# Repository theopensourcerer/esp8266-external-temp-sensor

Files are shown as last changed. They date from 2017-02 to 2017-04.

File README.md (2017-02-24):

# ESP8266 External Temp Sensor

This is simple board which will connect to one of those DS18B20 temperature sensors which are inside a metal sleeve and designed for external use. 

This board will ultimately live in a box outside my polytunnel with a 12V car battery, charged using solar power. One of the new features of this particular design, for me at least, is using a Switching regulator rather than a nomral LDO Linear regulator. I read that trying to drop from 12v to 3.3v is not effecient at all and can generate a lot of heat using a Linear design.

The board's software (under active testing & development) will take a measurememt, send it over MQTT and go back to sleep. I wanted this so I could compare the temperature between inside my polytunnel (see https://github.com/theopensourcerer/esp8266_envmonitor) and the normal outdoor temperature.

As with the Environment Monitor Project I plan to publish the code and a 3D case for this design. Watch this space!

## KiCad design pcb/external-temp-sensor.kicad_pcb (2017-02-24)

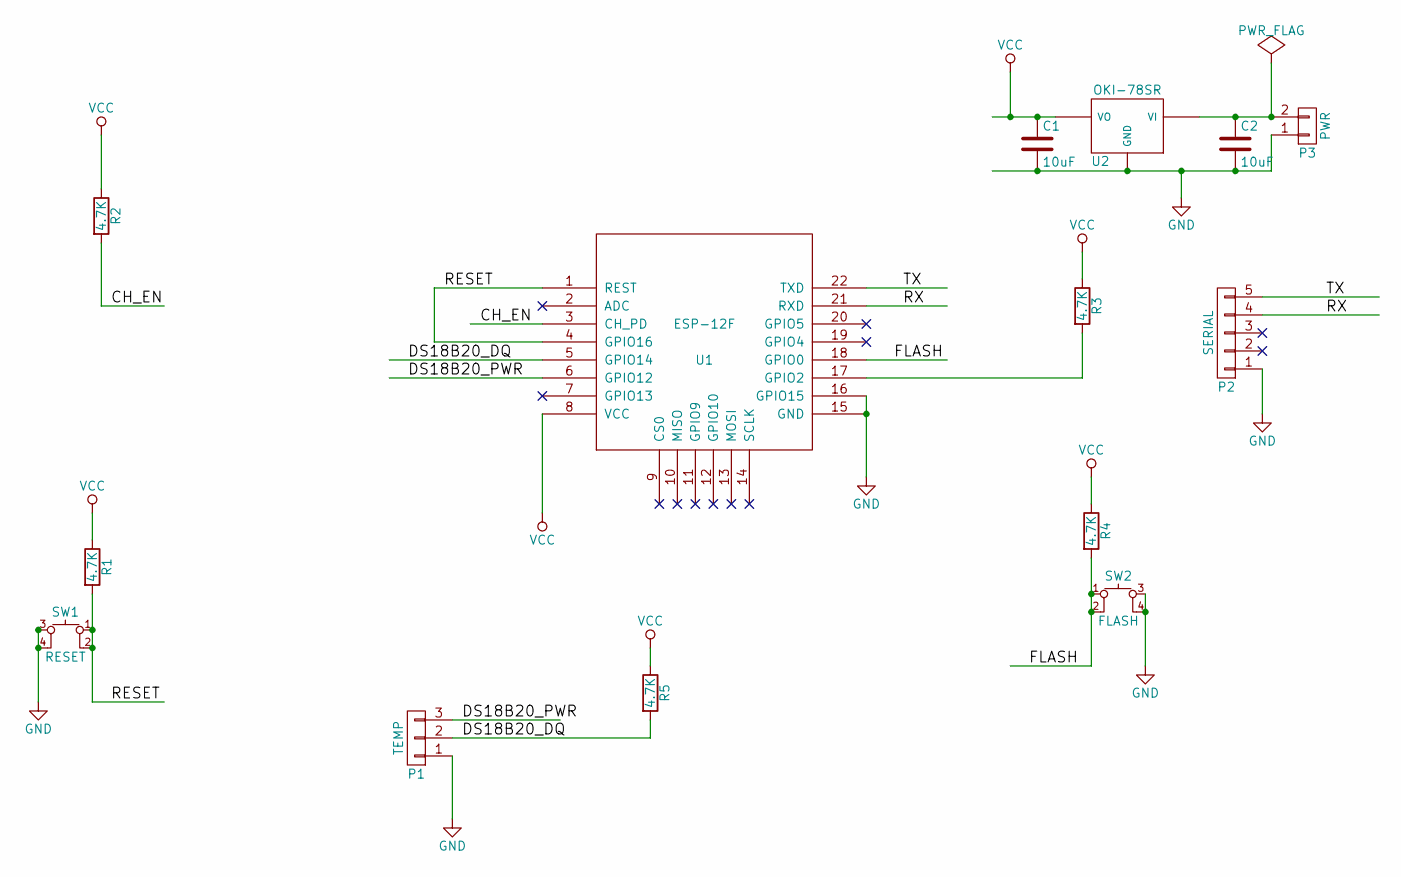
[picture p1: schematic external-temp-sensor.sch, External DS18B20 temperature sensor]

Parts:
C1, C2: 10uF; C_1206_HandSoldering
P1: TEMP; JST_XH_B03B-XH-A_03x2.50mm_Straight
P2: SERIAL; Pin_Header_Straight_1x05_Pitch2.54mm
P3: PWR; JST_XH_B02B-XH-A_02x2.50mm_Straight
R1, R2, R3, R4, R5: 4.7K; R_1206_HandSoldering
SW1: RESET; SKQGAFE010_Switch
SW2: FLASH; SKQGAFE010_Switch
U1: ESP-12F; ESP-12E
U2: OKI-78SR

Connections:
/CH_EN: R2.2, U1.3 (CH_PD)
/DS18B20_DQ: P1.2, R5.2, U1.5 (GPIO14)
/DS18B20_PWR: P1.3, U1.6 (GPIO12)
/FLASH: R4.2, SW2.1, SW2.2, U1.18 (GPIO0)
/RESET: R1.2, SW1.1, SW1.2, U1.1 (REST), U1.4 (GPIO16)
/RX: P2.4, U1.21 (RXD)
/TX: P2.5, U1.22 (TXD)
GND: C1.2, C2.2, P1.1, P2.1, P3.1, SW1.3, SW1.4, SW2.3, SW2.4, U1.15 (GND), U1.16 (GPIO15), U2.2 (GND)
unnamed: C2.1, P3.2, U2.1 (VI)
unnamed: R3.2, U1.17 (GPIO2)
VCC: C1.1, R1.1, R2.1, R3.1, R4.1, R5.1, U1.8 (VCC), U2.3 (VO)

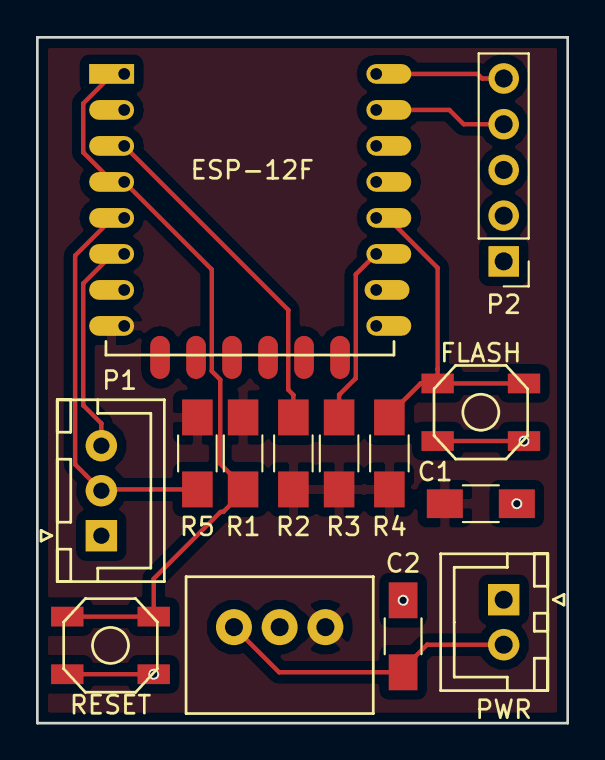
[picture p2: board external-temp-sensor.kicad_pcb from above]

Board: 2 copper layers, 29.5 x 38.1 mm, 14 parts (0 on the bottom side), 11 nets.

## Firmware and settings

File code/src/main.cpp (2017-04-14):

/*
External Temperature Sensor

For the Espressif ESP8266

Uses MQTT and a DS18B20 Sensor to read and transmit Temprature to an MQTT
Broker.

This code was written and tested using the PlatformIO IDE and the ESP8266-12F
module.

Ideas and code from various soruces:
https://github.com/chaeplin/esp8266_and_arduino
https://twitter.com/jpwsutton,

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
This code is licensed under the GNU LGPL and is open for ditrbution
and copying in accordance with the license.
This header must be included in any derived code or copies of the code.

(C) Alan Lord 2017
*/
#include "config.h"

#include <ESP8266WiFi.h>
#include <PubSubClient.h>
#include <OneWire.h>
#include <DallasTemperature.h>
#include <ArduinoJson.h>

// Set up ESP8266 ADC for voltage read
ADC_MODE(ADC_VCC);
float vcc;

// DS18B20
float temp(NAN);

// Timer placeholders
unsigned long startMills = 0;

// Function Prototypes
void readDS();
void setup_wifi();
void reconnect();
void publishJSON();
void goingToSleep();
// End Prototypes

// Begin code
WiFiClient espClient;
PubSubClient client(espClient);
OneWire oneWire(ONE_WIRE_BUS);

// Pass our oneWire reference to Dallas Temperature.
DallasTemperature DS18B20(&oneWire);
char temperatureCString[6];

void setup() {
  startMills = millis();
  //Power the DS18B20
  pinMode(ONE_WIRE_PWR, OUTPUT);
  digitalWrite(ONE_WIRE_PWR, HIGH);
  vcc = ESP.getVcc();
  Serial.begin(115200);
  DS18B20.begin();

  setup_wifi();
  client.setServer(MQTT_SERVER, 1883);
}

void setup_wifi() {
  // We start by connecting to a WiFi network
  if (DEBUG_PRINT) {
    Serial.println();
    Serial.print("Connecting to ");
    Serial.println(WIFI_SSID);
  }
  WiFi.begin(WIFI_SSID, WIFI_PASSWORD);

  while (WiFi.status() != WL_CONNECTED) {
    delay(500);
    Serial.print(".");
  }

  if (DEBUG_PRINT) {
    Serial.println("");
    Serial.println("WiFi connected");
    Serial.println("IP address: ");
    Serial.println(WiFi.localIP());
  }
}

void loop() {
  if (!client.connected()) {
    reconnect();
  }

  readDS();

  if(temp) {
    if (DEBUG_PRINT) {
      Serial.print("Read DS18B20. Publish message: ");
    }
    publishJSON();
  }
  goingToSleep();
}

void reconnect() {
  // Loop until we're reconnected
  while (!client.connected()) {
    if (DEBUG_PRINT) {
      Serial.print("Attempting MQTT connection...");
    }
    // Attempt to connect
    if (client.connect("EXTMonitor")) {
      if (DEBUG_PRINT) {
        Serial.println("Connected");
      }
    } else {
      if (DEBUG_PRINT) {
        Serial.print("Failed to connect. State = ");
        Serial.print(client.state());
        Serial.println(" Retry in 2 seconds");
      }
      // Wait 2 seconds before retrying
      delay(2000);
    }
  }
}

void publishJSON() {
  if (client.connected()) {
    StaticJsonBuffer<175> jsonBuffer;
    JsonObject& root = jsonBuffer.createObject();
    JsonArray& payload = root.createNestedArray("payload");
    JsonObject& data = payload.createNestedObject();
    data["sensorid"] = SENSORNAME;
    data["temp"] = temp;
    data["vcc"] = vcc/1000;
    data["cycletime"] = millis() - startMills;
    if (DEBUG_PRINT) {
      Serial.print("Sending payload: ");
      root.prettyPrintTo(Serial);
    }

    char buffer[150];
    root.printTo(buffer, sizeof(buffer));
    if (client.publish(TOPIC, buffer));
      if (DEBUG_PRINT) {
        Serial.print("Published OK  --> ");
        Serial.println(millis() - startMills);
      }
    } else {
      if (DEBUG_PRINT) {
        Serial.print("Publish failed --> ");
        Serial.println(millis() - startMills);
      }
    }
}

void readDS() {
  do {
    DS18B20.requestTemperatures();
    temp = DS18B20.getTempCByIndex(0);
    dtostrf(temp, 2, 2, temperatureCString);
    delay(100);
    if (DEBUG_PRINT) {
      Serial.print("Temp: ");
      Serial.print(temp);
    }
    if((millis() - startMills) > 10000) {
      if (DEBUG_PRINT) {
        Serial.print("Failed to read from DS18B20 within time limit ");
        Serial.print(millis() - startMills);
        Serial.print("Going to sleep");
      }
      goingToSleep();
    }
  } while (temp == 85.0 || temp == (-127.0));
}

void goingToSleep() {
  // All Good
  if (DEBUG_PRINT) {
    Serial.print("About to go to sleep: Time taken to complete cycle: ");
    Serial.println(millis() - startMills);
  }
  client.disconnect();
  yield();
  WiFi.disconnect();
  WiFi.mode(WIFI_OFF);
  WiFi.forceSleepBegin();
  ESP.deepSleep(deep_sleep, DS_MODE);
  //ESP.deepSleep(0);
  delay(250);
}

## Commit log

2017-02-23 Added page and license information.
    [external-temp-sensor.kicad_pcb, external-temp-sensor.sch]
2017-02-24 Add pull-up resistor
    [external-temp-sensor.kicad_pcb, external-temp-sensor.sch]
2017-04-14 Switch to a JSON payload over MQTT and other minor changes

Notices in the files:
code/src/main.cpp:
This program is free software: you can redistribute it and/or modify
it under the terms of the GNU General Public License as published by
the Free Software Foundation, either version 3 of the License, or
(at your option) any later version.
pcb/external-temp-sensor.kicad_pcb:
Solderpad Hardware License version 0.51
